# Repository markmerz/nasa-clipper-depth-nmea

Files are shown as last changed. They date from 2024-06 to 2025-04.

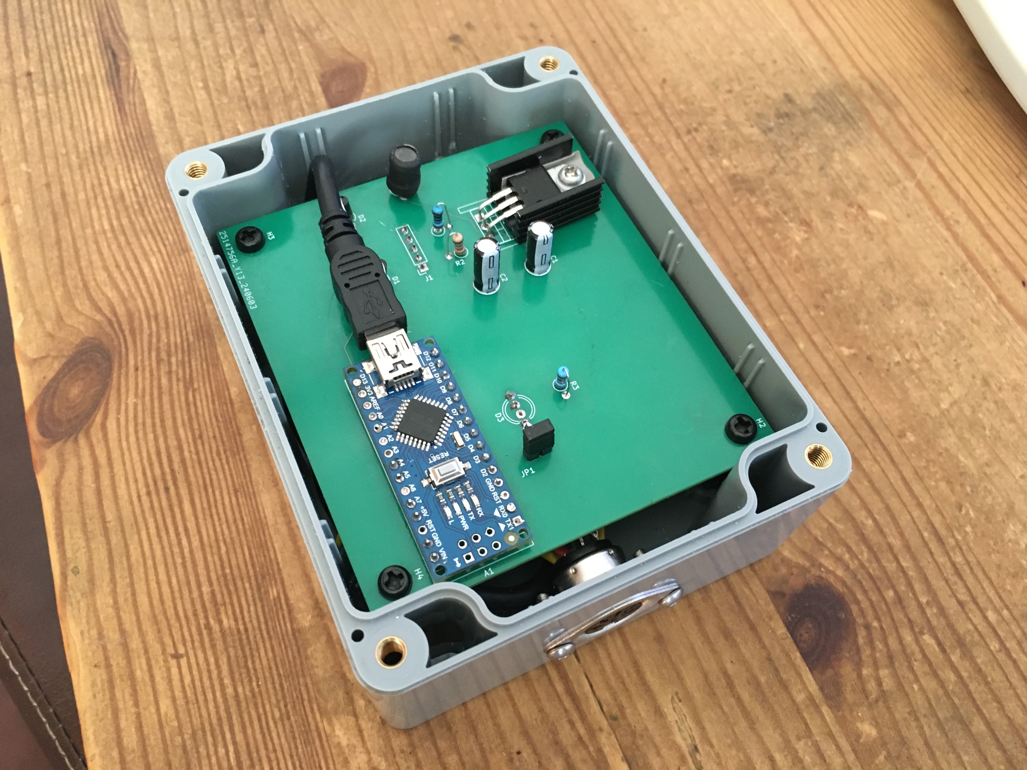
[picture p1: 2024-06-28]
showoff/open-box.jpg

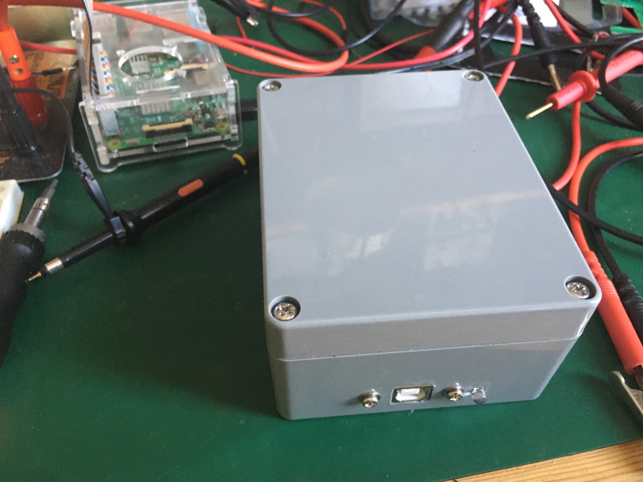
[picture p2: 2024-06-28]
showoff/closed-box.jpg

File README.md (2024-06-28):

# nasa-clipper-depth-nmea
NMEA0183 converter to NASA Clipper Depth sounder.

An affordable depth sounder, the "NASA Clipper Depth" does not have NMEA0183 output.
It has an I2C output for driving a secondary display. This project taps into
I2C output, decodes display driving protocol, creates NMEA0103 messages from
it and sends them over USB-SERIAL link for distributing with other devices.

This project is heavily inspired by https://wiki.openseamap.org/wiki/De:NASA_Clipper_Range

As of 28.06.2024, the PCB part of the project is in its final form. Arduino code is partial,
lacking actual decoding and recoding parts. I intend to install the device to the boat
and observe the actual protocol on the wire, as I feel this protocol is slightly
different between device versions.

PCB is designed to fit into a sealed plastic box I had lying around. Unfortunately, I don't
remember when and from where I got the box, so I can't provide a reference for where you could get
the same enclosure. The box measures 11.3 x 8.9 x 5.5 centimetres, made from hard grey plastic.

PCB cost about 11€ delivered into the EU, ordered from jlcpcb.com. Manufacturer
website also handles taxes and customs. DIN5 connectors were ~15€, arduino-compatible board was 
~5€, the enclosure was probably ~10€, and the rest of the parts were jellybeans from the box.

My point is that when you don't particularly like tinkering with electronics, it may be 
wiser to buy an echosounder that already has NMEA0183 or even NMEA2000 output. But when you like 
building things, this project is an excellent way to save costs, although it requires You to pay 
a little more.

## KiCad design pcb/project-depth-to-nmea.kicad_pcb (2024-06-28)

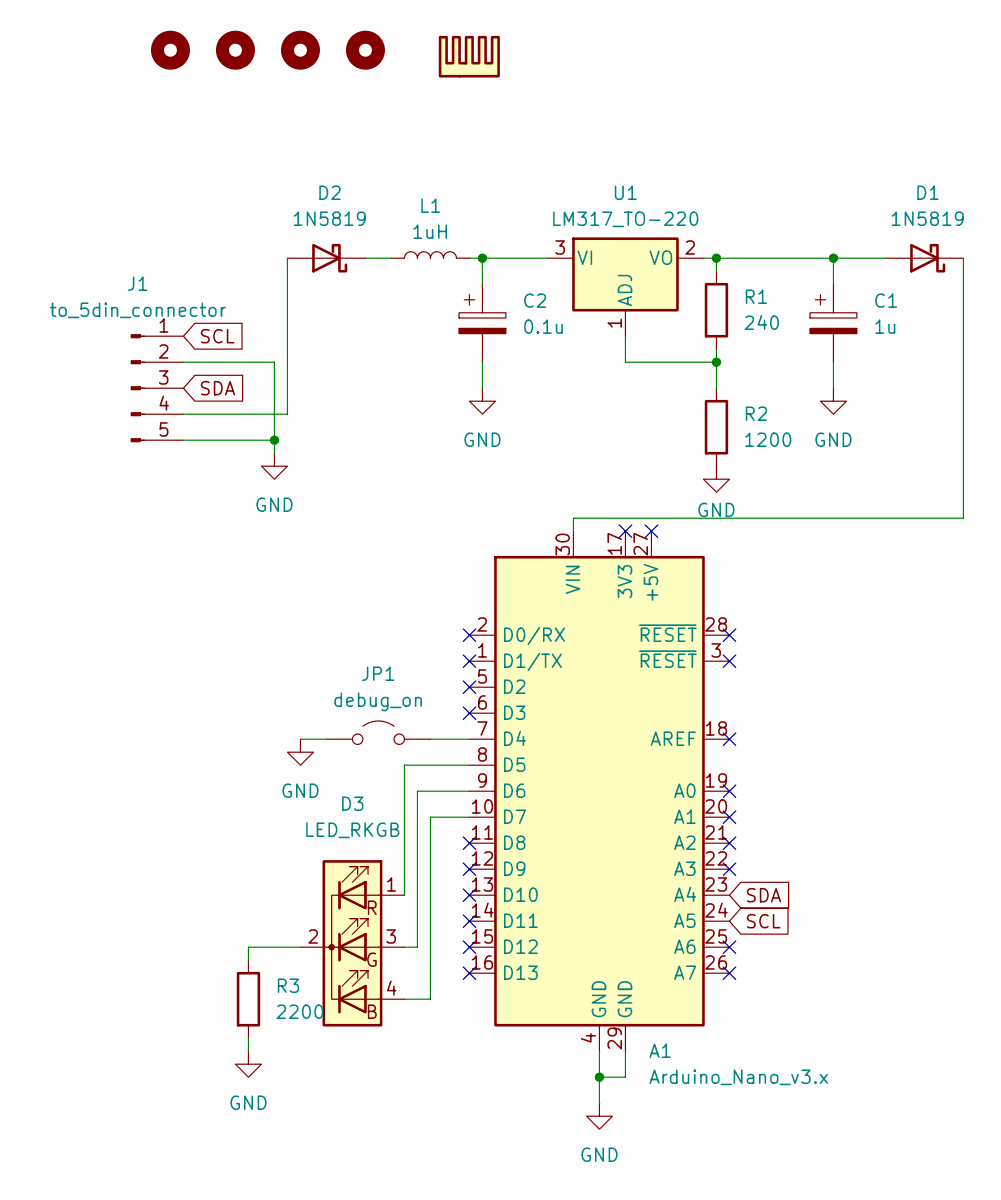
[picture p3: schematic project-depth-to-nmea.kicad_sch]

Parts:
A1: Arduino_Nano_v3.x; Arduino_Nano
C1: 1u; CP_Radial_D5.0mm_P2.50mm
C2: 0.1u; CP_Radial_D5.0mm_P2.50mm
D1, D2: 1N5819; D_DO-41_SOD81_P2.54mm_Vertical_AnodeUp
D3: LED_RKGB; LED_D5.0mm-4_RGB_Wide_Pins
H1, H2, H3, H4: MountingHole; MountingHole_3.2mm_M3
HS1: Heatsink; Heatsink_Stonecold_HS-S02_13.21x9.53mm
J1: to_5din_connector; PinSocket_1x05_P2.54mm_Vertical
JP1: debug_on; TestPoint_2Pads_Pitch2.54mm_Drill0.8mm
L1: 1uH; L_Axial_L9.5mm_D4.0mm_P2.54mm_Vertical_Fastron_SMCC
R1: 240; R_Axial_DIN0207_L6.3mm_D2.5mm_P2.54mm_Vertical
R2: 1200; R_Axial_DIN0207_L6.3mm_D2.5mm_P2.54mm_Vertical
R3: 2200; R_Axial_DIN0207_L6.3mm_D2.5mm_P2.54mm_Vertical
U1: LM317_TO-220; TO-220-3_Vertical

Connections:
GND: A1.4 (GND), A1.29 (GND), C1.2, C2.2, J1.2, J1.5, JP1.1 (A), R2.2, R3.2
unnamed: A1.7 (D4), JP1.2 (B)
unnamed: A1.8 (D5), D3.1 (RA)
unnamed: A1.9 (D6), D3.3 (GA)
unnamed: A1.10 (D7), D3.4 (BA)
unnamed: A1.30 (VIN), D1.1 (K)
unnamed: C1.1, D1.2 (A), R1.1, U1.2 (VO)
unnamed: D2.2 (A), J1.4
unnamed: D2.1 (K), L1.1
unnamed: D3.2 (K), R3.1
unnamed: R1.2, R2.1, U1.1 (ADJ)
unnamed: C2.1, L1.2, U1.3 (VI)
SCL: A1.24 (A5), J1.1
SDA: A1.23 (A4), J1.3

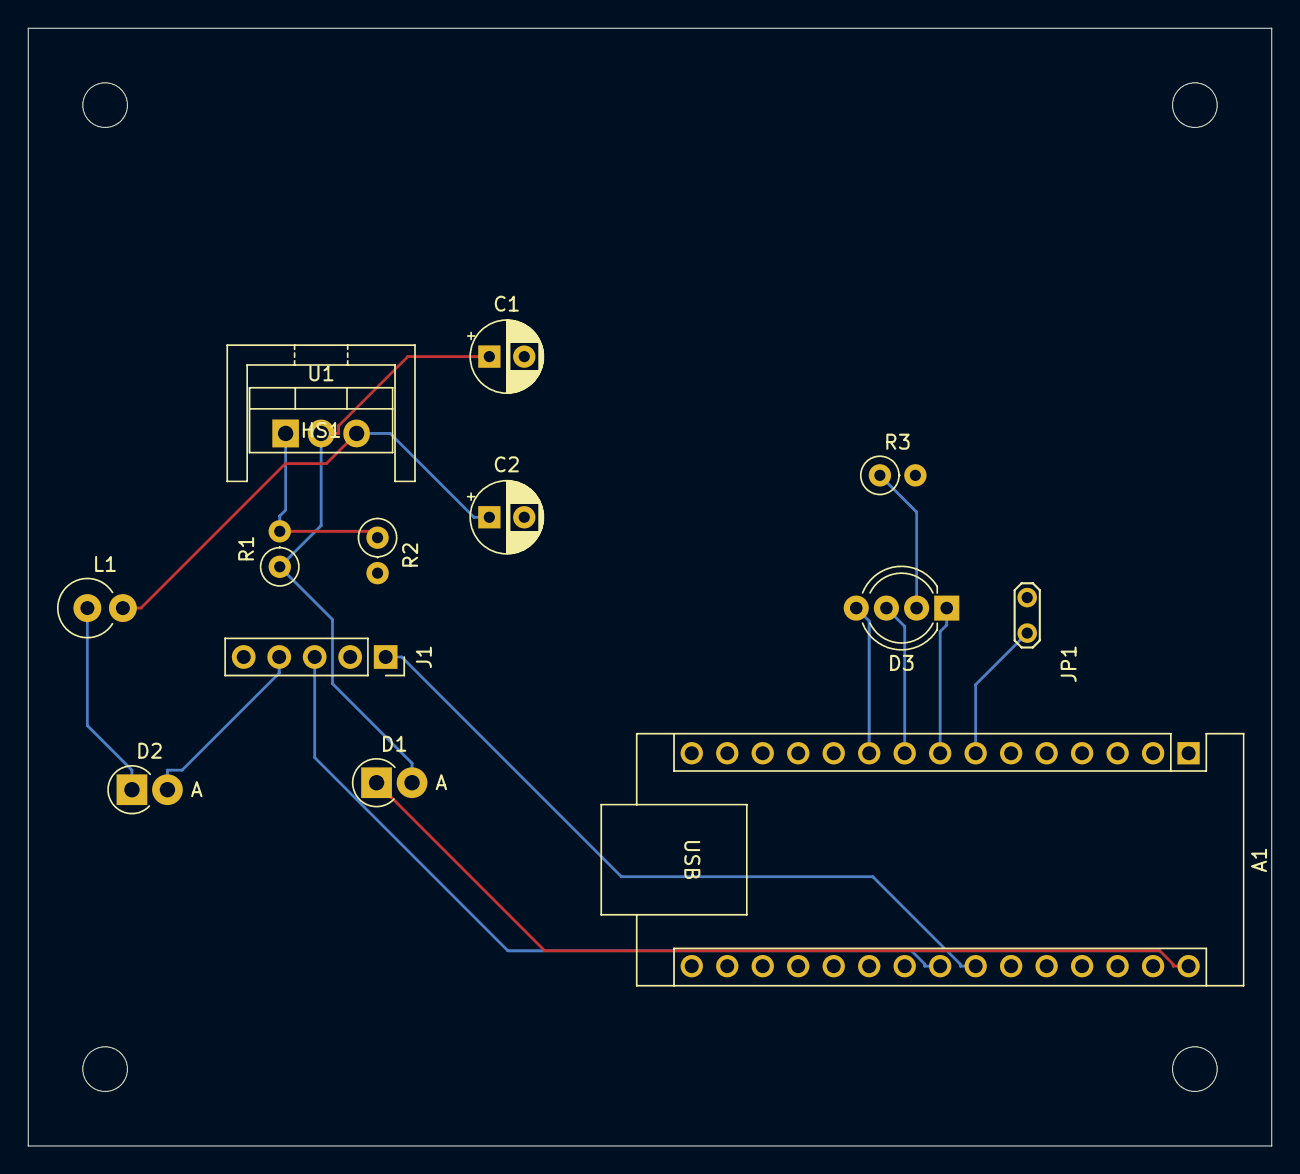
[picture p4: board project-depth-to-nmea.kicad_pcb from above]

Board: 2 copper layers, 89.0 x 80.0 mm, 18 parts (0 on the bottom side), 14 nets.

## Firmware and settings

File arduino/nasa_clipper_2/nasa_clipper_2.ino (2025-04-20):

 /*
  * Signal LED:
  *   Nothing received from I2C: solid red.
  *   Something received from I2C, but can not decode: blinking red.
  *   Received and decoded to nmea0183: solid green.
  *   Received and outputed as debug data: solid blue.
  *
  * Debug jumper:
  *   Open: normal mode.
  *   Shorted: debug mode.
  */


// #define MY_DEBUG

#define ECHOSOUNDER_DEPTH "0.5"
#define ECHOSOUNDER_MAX_VALUE "99.9"

#include <Wire.h>

#define TIMER_INTERRUPT_DEBUG      0
#define USE_TIMER_1     true
#define USE_TIMER_2     false
#define USE_TIMER_3     false
#define USE_TIMER_4     false
#define USE_TIMER_5     false
#include "TimerInterrupt.h"

uint16_t debug_counter = 0;
volatile uint16_t status_received = 10;
volatile uint16_t status_decoded = 10;
volatile uint8_t second_has_passed = 0;

#define LED_OFF 0
#define LED_RED 5
#define LED_GREEN 6
#define LED_BLUE 7
#define DEBUG_PIN 4
#define BLINK true
#define NO_BLINK false

bool blink_led = 0;
bool blink_cycle = 0;
uint8_t current_led = 0;

const uint64_t S1_mask      = 0b0000000000000000110000000010111100000000000000000000000000000000;
const uint64_t S1_0         = 0b0000000000000000110000000010111000000000000000000000000000000000;
const uint64_t S1_1         = 0b0000000000000000010000000000010000000000000000000000000000000000;
const uint64_t S1_2         = 0b0000000000000000100000000010011100000000000000000000000000000000;
const uint64_t S1_3         = 0b0000000000000000110000000010010100000000000000000000000000000000;
const uint64_t S1_4         = 0b0000000000000000010000000000110100000000000000000000000000000000;
const uint64_t S1_5         = 0b0000000000000000110000000010100100000000000000000000000000000000;
const uint64_t S1_6         = 0b0000000000000000110000000010101100000000000000000000000000000000;
const uint64_t S1_7         = 0b0000000000000000010000000010010000000000000000000000000000000000;
const uint64_t S1_8         = 0b0000000000000000110000000010111100000000000000000000000000000000;
const uint64_t S1_9         = 0b0000000000000000110000000010110100000000000000000000000000000000;
const uint64_t S1[]         = {S1_0, S1_1, S1_2, S1_3, S1_4, S1_5, S1_6, S1_7, S1_8, S1_9};

const uint64_t S2_mask      = 0b0000000000000000000000000000000000000000000000000000000011111110;
const uint64_t S2_0         = 0b0000000000000000000000000000000000000000000000000000000011101110;
const uint64_t S2_1         = 0b0000000000000000000000000000000000000000000000000000000001000100;
const uint64_t S2_2         = 0b0000000000000000000000000000000000000000000000000000000010110110;
const uint64_t S2_3         = 0b0000000000000000000000000000000000000000000000000000000011010110;
const uint64_t S2_4         = 0b0000000000000000000000000000000000000000000000000000000001011100;
const uint64_t S2_5         = 0b0000000000000000000000000000000000000000000000000000000011011010;
const uint64_t S2_6         = 0b0000000000000000000000000000000000000000000000000000000011111010;
const uint64_t S2_7         = 0b0000000000000000000000000000000000000000000000000000000001000110;
const uint64_t S2_8         = 0b0000000000000000000000000000000000000000000000000000000011111110;
const uint64_t S2_9         = 0b0000000000000000000000000000000000000000000000000000000011101110;
const uint64_t S2[]         = {S2_0, S2_1, S2_2, S2_3, S2_4, S2_5, S2_6, S2_7, S2_8, S2_9};

const uint64_t S3_mask      = 0b0000000000000000000000000000000000000000000000001011111100000000;
const uint64_t S3_0         = 0b0000000000000000000000000000000000000000000000001011101100000000;
const uint64_t S3_1         = 0b0000000000000000000000000000000000000000000000000001000100000000;
const uint64_t S3_2         = 0b0000000000000000000000000000000000000000000000001001111000000000;
const uint64_t S3_3         = 0b0000000000000000000000000000000000000000000000001001011100000000;
const uint64_t S3_4         = 0b0000000000000000000000000000000000000000000000000011010100000000;
const uint64_t S3_5         = 0b0000000000000000000000000000000000000000000000001010011100000000;
const uint64_t S3_6         = 0b0000000000000000000000000000000000000000000000001010111100000000;
const uint64_t S3_7         = 0b0000000000000000000000000000000000000000000000001001000100000000;
const uint64_t S3_8         = 0b0000000000000000000000000000000000000000000000001011111100000000;
const uint64_t S3_9         = 0b0000000000000000000000000000000000000000000000001011011100000000;
const uint64_t S3[]         = {S3_0, S3_1, S3_2, S3_3, S3_4, S3_5, S3_6, S3_7, S3_8, S3_9};

const uint64_t DEPTH_mask   = 0b0000000000000000000000000000000000000000000000000000000000000001;
const uint64_t DEPTH        = 0b0000000000000000000000000000000000000000000000000000000000000001;
const uint64_t METERS_mask  = 0b0000000000000000000000000000000001000000000000000000000000000000;
const uint64_t METERS       = 0b0000000000000000000000000000000001000000000000000000000000000000;
const uint64_t FEET_mask    = 0b0000000000000000000000000000000000000000000000010000000000000000;
const uint64_t FEET         = 0b0000000000000000000000000000000000000000000000010000000000000000;
const uint64_t DECIMAL_mask = 0b0000000000000000000000000000000010000000000000000000000000000000;
const uint64_t DECIMAL      = 0b0000000000000000000000000000000010000000000000000000000000000000;


typedef union {
  uint8_t asarray[8];
  uint64_t asint = 0;
} data_t;

void setup() {
  pinMode(LED_BUILTIN, OUTPUT);
  pinMode(LED_RED, OUTPUT);
  pinMode(LED_GREEN, OUTPUT);
  pinMode(LED_BLUE, OUTPUT);
  pinMode(DEBUG_PIN, INPUT_PULLUP);
  
  Serial.begin(9600);

  Wire.begin(0x3e);
  Wire.onReceive(receiveEvent);

  ITimer1.init();
  ITimer1.attachInterruptInterval(1000, TimerHandler1);
}

void loop() {
  if (status_received > 3) {
    set_signal_led(LED_RED, NO_BLINK);
  } else if (status_decoded > 3) {
    set_signal_led(LED_RED, BLINK);
  } else {
    if (digitalRead(DEBUG_PIN) == HIGH) {
      set_signal_led(LED_GREEN, NO_BLINK);
    } else {
      set_signal_led(LED_BLUE, NO_BLINK);
    }
  }

  do_blinking();
  
  delay(500);
}

void receiveEvent(int howMany) {
  if (digitalRead(DEBUG_PIN) == LOW) {
    // write debug info and hex bytes to usb output
    Serial.print("C: ");
    Serial.print(debug_counter++);

    Serial.print(" A: ");
    Serial.print(Wire.available());

    Serial.print(" H: ");
    Serial.print(howMany);
    Serial.print(" MSG: ");

    while(Wire.available() > 0) {
      uint8_t x = Wire.read();
      print_hex_byte(x);
    }
    Serial.println();
    status_received = 0;
    status_decoded = 0;
  } else {
    // recode to nmea0183 to usb output
    data_t data;
    if (howMany == 12) {
      for(int c = 0; c < howMany; c++) {
        uint8_t x = Wire.read();
        if (c >= 6) {
          data.asarray[c-6] = x;
        }
      }
      status_received = 0;

      #ifdef MY_DEBUG
      Serial.print("data As array: ");
      for (int c = 0; c < 8; c++) {
        print_hex_byte(data.asarray[c]);
      }
      Serial.println();

      Serial.print("data As uint64: ");
      // print64(data.asint);
      println64(&Serial, data.asint);
      // Serial.println();

      Serial.print("S1 mask: ");
      println64(&Serial, S1_mask);

      Serial.print("data & S1 mask: ");
      println64(&Serial, data.asint & S1_mask);
      #endif

      uint64_t tmp = data.asint & S1_mask;
      int8_t nr1 = -1;
      for (int c = 0; c < 10; c++) {
        if (S1[c] == tmp) {
          nr1 = c;
          break;
        }
      }

      #ifdef MY_DEBUG
      Serial.print("S1: ");
      Serial.println(nr1);
      #endif
      
      tmp = data.asint & S2_mask;
      int8_t nr2 = -1;
      for (int c = 0; c < 10; c++) {
        if (S2[c] == tmp) {
          nr2 = c;
          break;
        }
      }

      #ifdef MY_DEBUG
      Serial.print("S2: ");
      Serial.println(nr2);
      #endif

      tmp = data.asint & S3_mask;
      int8_t nr3 = -1;
      for (int c = 0; c < 10; c++) {
        if (S3[c] == tmp) {
          nr3 = c;
          break;
        }
      }

      #ifdef MY_DEBUG
      Serial.print("S3: ");
      Serial.println(nr3);
      #endif

      // check if depth indicator is on,
      // means that we have reliable reading
      if (second_has_passed && (data.asint & DEPTH_mask == DEPTH)) {
        second_has_passed = 0;
        
        float result_in_meters = 0;
        // nr1 can be blank
        if (nr1 > 0) {
          result_in_meters += nr1 * 100;
        }

        if (nr2 == -1) return;
        result_in_meters += nr2 * 10;

        if (nr3 == -1) return;
        result_in_meters += nr3;

        if (data.asint & DECIMAL_mask == DECIMAL) {
          result_in_meters = result_in_meters * 0.1;
        }

        if (data.asint & FEET_mask == FEET) {
          result_in_meters = result_in_meters * 0.3048;
        }

        // by default floats are not supperted by printf.
        // lets work around here as enabling them means changeing "boards.txt" file.
        int result_int = (int) result_in_meters;
        int result_dec = ((int) (result_in_meters * 10)) % 10;
        char nmea_sub_sentence[32];
        char nmea_full_sentence[128];
        sprintf(nmea_sub_sentence, "YXDPT,%i.%i,%s,%s", result_int, result_dec, ECHOSOUNDER_DEPTH, ECHOSOUNDER_MAX_VALUE);
        char* checksum = calculate_nmea_checksum(nmea_sub_sentence);
        sprintf(nmea_full_sentence, "$%s*%s\r\n", nmea_sub_sentence, checksum);
        Serial.print(nmea_full_sentence);
        status_decoded = 0;
      }

    } else {
      // consume wire and declare error
      while(Wire.available() > 0) {
        volatile int x = Wire.read();
      }
      status_received = 0;
    }
  }
}

char* calculate_nmea_checksum(char* sentence) {
  static char checksum_str[8];
  uint8_t checksum = 0;
  for (int c = 0; sentence[c] != 0 && c < 256; c++) {
    checksum = checksum ^ (uint8_t) sentence[c];
  }

  sprintf(checksum_str, "%02X", checksum);
  return checksum_str;
}

void TimerHandler1(void) {
  if (status_received++ > 30000) status_received = 10;
  if (status_decoded++ > 30000) status_decoded = 10;
  if (second_has_passed++ > 200) second_has_passed = 120;
}

void set_signal_led(int led, bool blink) {
  current_led = led;
  switch (led) {
    case LED_RED:
      digitalWrite(LED_GREEN, LOW);
      digitalWrite(LED_BLUE, LOW);
      digitalWrite(LED_RED, HIGH);
      break;
    case LED_GREEN:
      digitalWrite(LED_RED, LOW);
      digitalWrite(LED_BLUE, LOW);
      digitalWrite(LED_GREEN, HIGH);
      break;
    case LED_BLUE:
      digitalWrite(LED_GREEN, LOW);
      digitalWrite(LED_RED, LOW);
      digitalWrite(LED_BLUE, HIGH);
      break;
    default:
      digitalWrite(LED_GREEN, LOW);
      digitalWrite(LED_BLUE, LOW);
      digitalWrite(LED_RED, LOW);
  }

  if (blink) {
    blink_led = 1;
  } else {
    blink_led = 0;
  }
}

void do_blinking() {
  // blue led does not semi-blink
  // mostly bc semiblinking was an afterthought
  // and blue led is connected to non-pwm pin.
  if (blink_led) {
    if (blink_cycle) {
      if (current_led == LED_BLUE) {
        set_signal_led(LED_OFF, blink_led);
      } else {
        analogWrite(current_led, 20);
      }
      blink_cycle = false;
    } else {
      set_signal_led(current_led, blink_led);
      blink_cycle = true;
    }
  } else {
    if (blink_cycle == false) {
      set_signal_led(current_led, blink_led);
      blink_cycle = true;
    }
  }

  // visual indicator that we sucessfully uploaded our firmware.
  // digitalWrite(LED_BUILTIN, !digitalRead(LED_BUILTIN));
}

void print_hex_byte(short num) {
  char tmp[4];
  sprintf(tmp, "%02X", num);
  Serial.print(tmp);
}

size_t print64(Print* pr, uint64_t n) {
  char buf[21];
  char *str = &buf[sizeof(buf) - 1];
  *str = '\0';
  do {
    uint64_t m = n;
    n /= 10;
    *--str = m - 10*n + '0';
  } while (n);
  pr->print(str);
}

size_t print64(Print* pr, int64_t n) {
  size_t s = 0;
  if (n < 0) {
    n = -n;
    s = pr->print('-');
  }  return s + print64(pr, (uint64_t)n);
}

size_t println64(Print* pr, int64_t n) {
  return print64(pr, n) + pr->println();
}

size_t println64(Print* pr, uint64_t n) {
  return print64(pr, n) + pr->println();
}
